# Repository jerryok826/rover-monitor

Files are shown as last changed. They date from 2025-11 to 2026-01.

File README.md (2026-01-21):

# Rover Monitor
Rover monitor is a simple info display for the JPL's open-source-rover project
# My initial Rover Testing
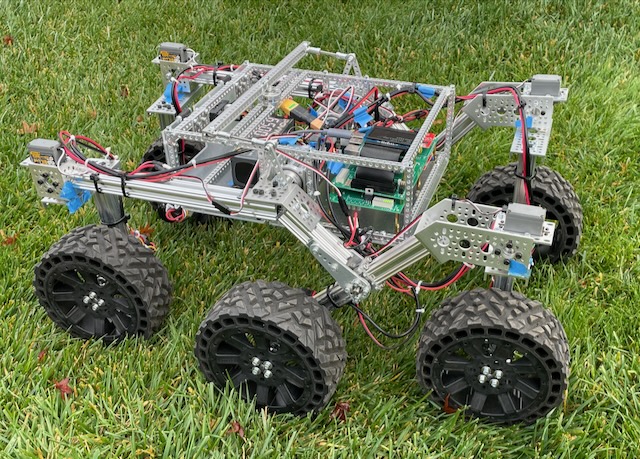
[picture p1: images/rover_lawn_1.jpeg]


# Rover info monitor.
### Rover ROS2 Off
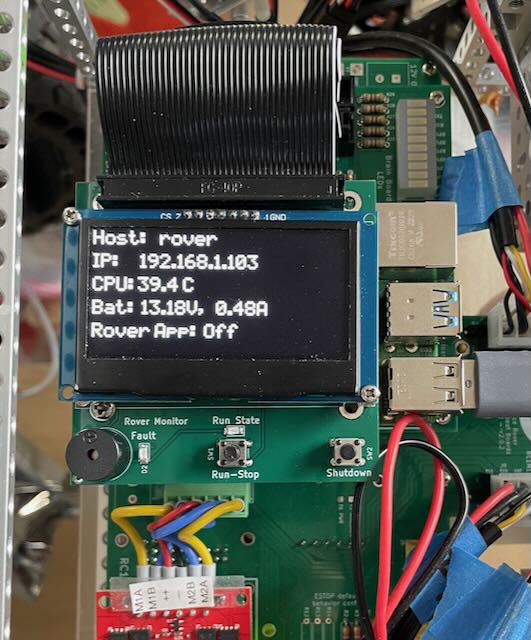
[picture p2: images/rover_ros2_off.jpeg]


### Rover ROS2 Running
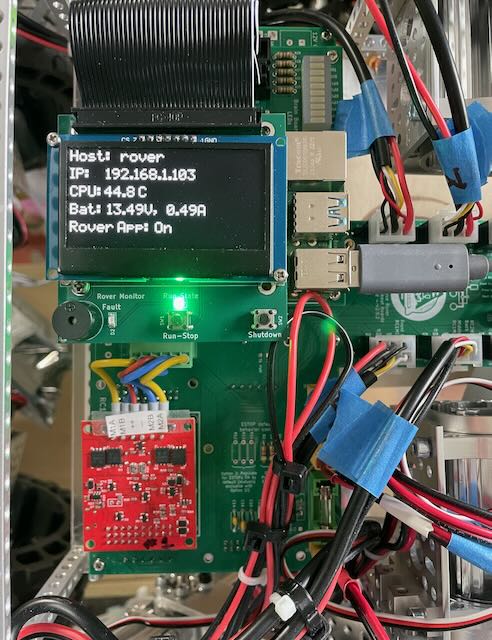
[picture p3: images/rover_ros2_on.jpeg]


### Voltage fault: Below 12.0 V
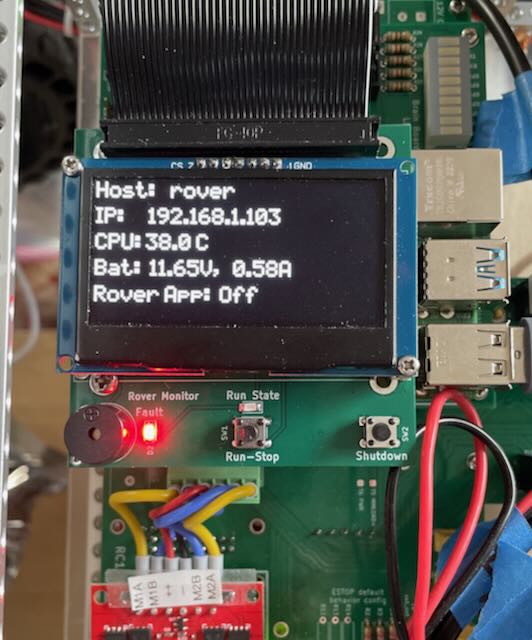
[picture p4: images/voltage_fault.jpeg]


## Rover Monitor Project Description
I wanted a convenient way to start/stop, shutdown and monitor the rover for problems. The board just uses the RPI's GPIO to drive the board with some C code. The code boots from startup and monitors the rover's battery voltage and current. It’s also convenient to have the rover's hostname for remote login. The V and I readings come from the rover's on board ina260 via i2c. Been using the board for login info and shutdown for about a month.

Monitor Features:
1. Local login info.
2. Rover shutdown button.
3. Rover ROS run and stop button.
4. Voltage and current monitoring with audio alarm on fault.
5. Monitor beeps when system has complteted booting and ready for operation.

### Project Status
Basically complete, except for a fault event detail line to the display. Below is the original prototype version.

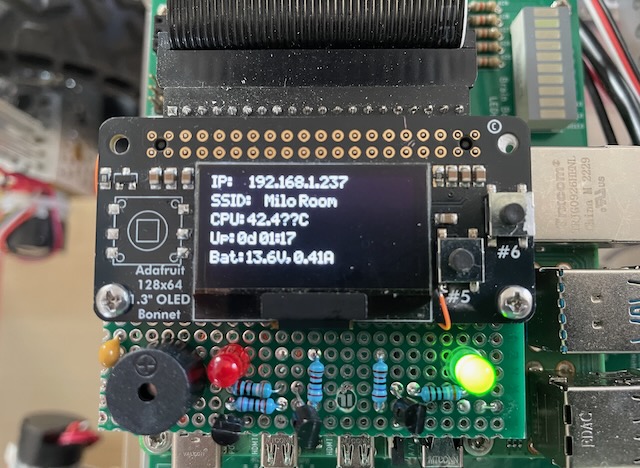
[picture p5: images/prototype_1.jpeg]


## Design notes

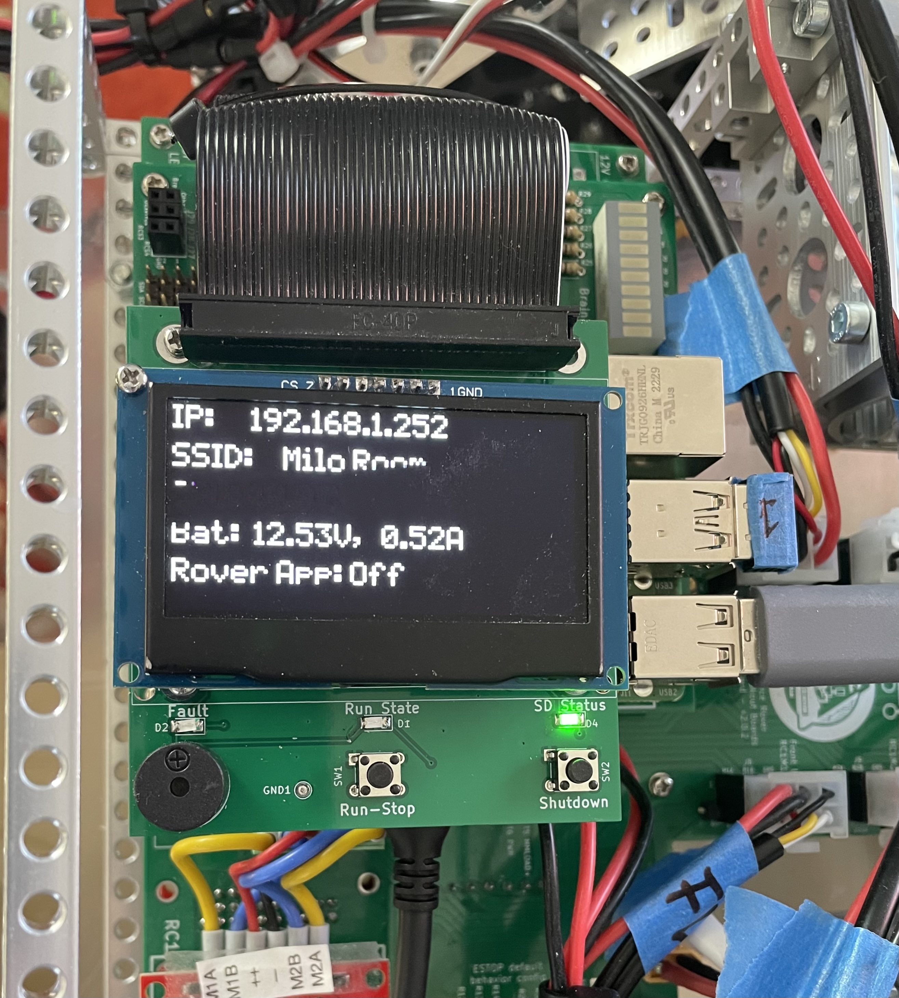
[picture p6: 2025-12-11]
images/rover_monitor_pcb.jpg

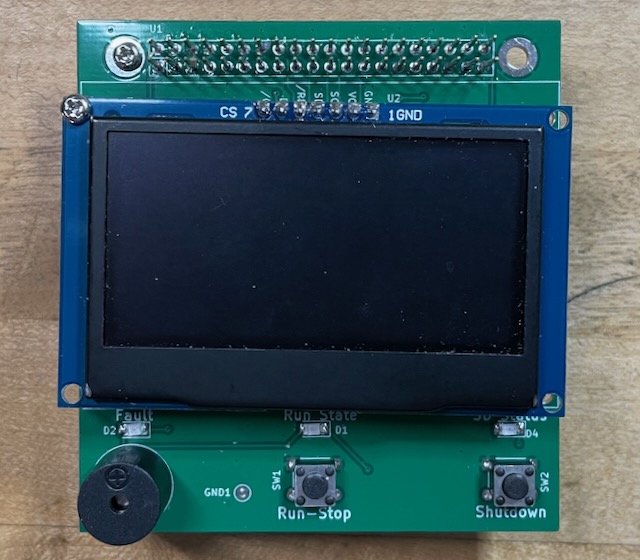
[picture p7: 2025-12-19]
images/oled_board_front.jpeg

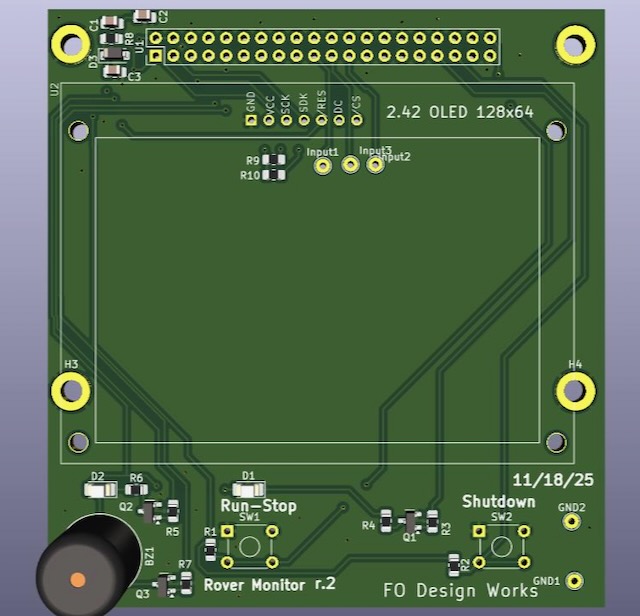
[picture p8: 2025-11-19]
images/rover_monitor_pcb_r2.jpeg

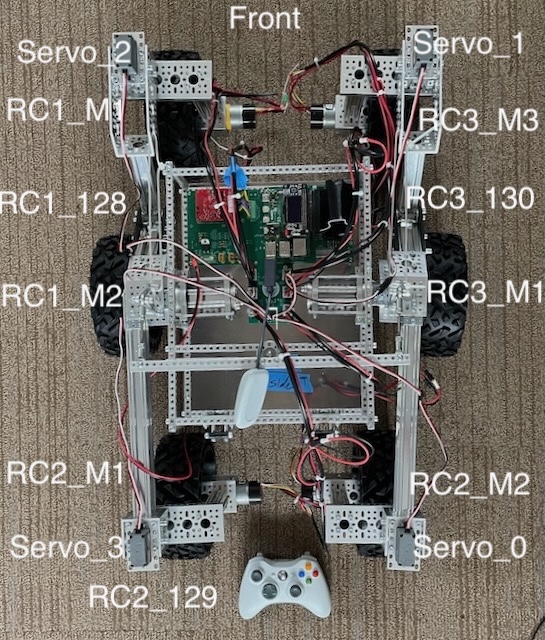
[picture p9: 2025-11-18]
images/jpl_rover_2.jpeg

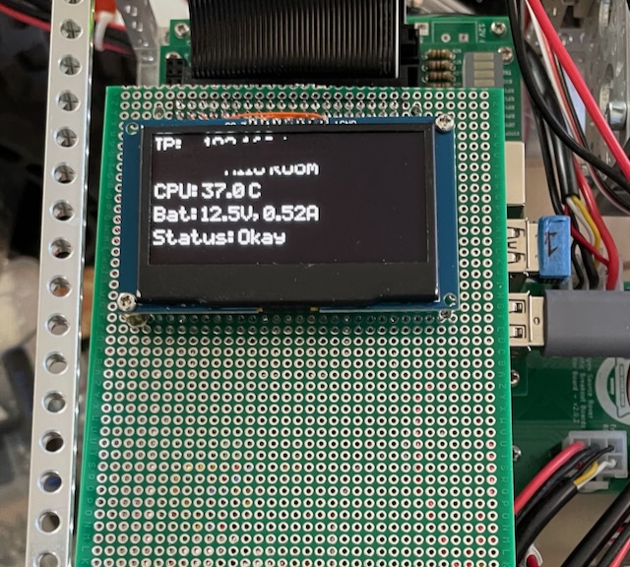
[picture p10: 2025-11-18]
images/oled_large.jpeg

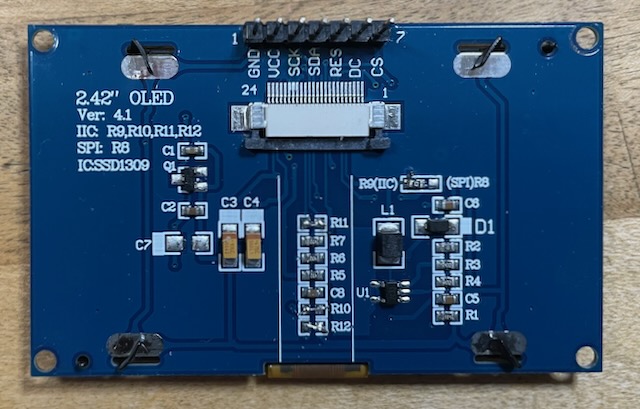
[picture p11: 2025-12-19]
images/oled_i2c.jpeg

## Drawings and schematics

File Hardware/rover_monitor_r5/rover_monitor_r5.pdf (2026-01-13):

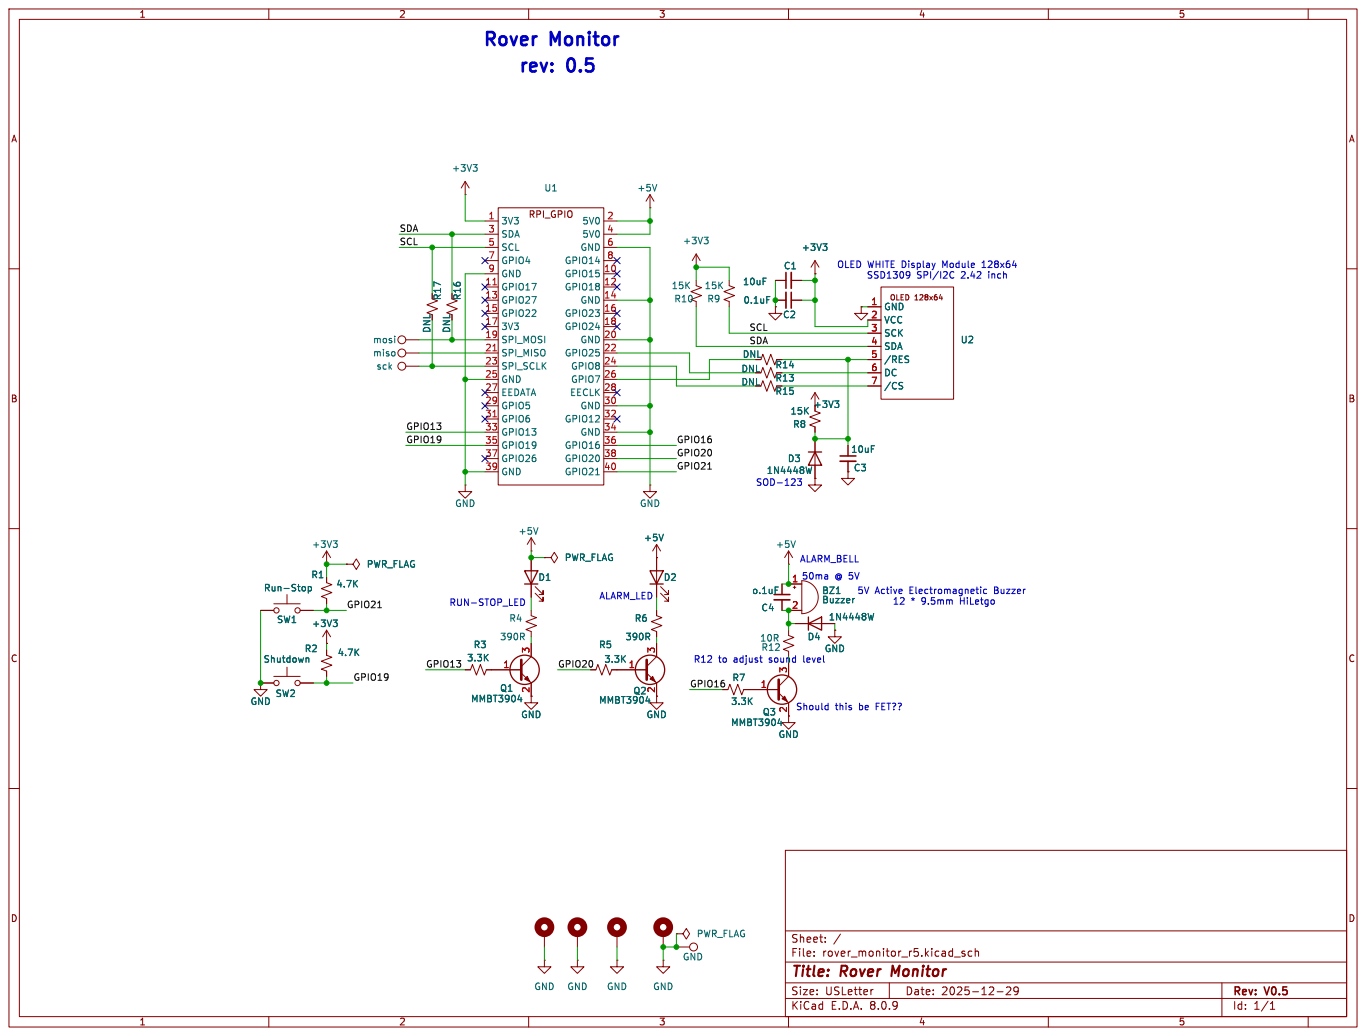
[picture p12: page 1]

Id: 1/1 Title: Rover Monitor File: rover_monitor_r5.kicad_sch Sheet: /

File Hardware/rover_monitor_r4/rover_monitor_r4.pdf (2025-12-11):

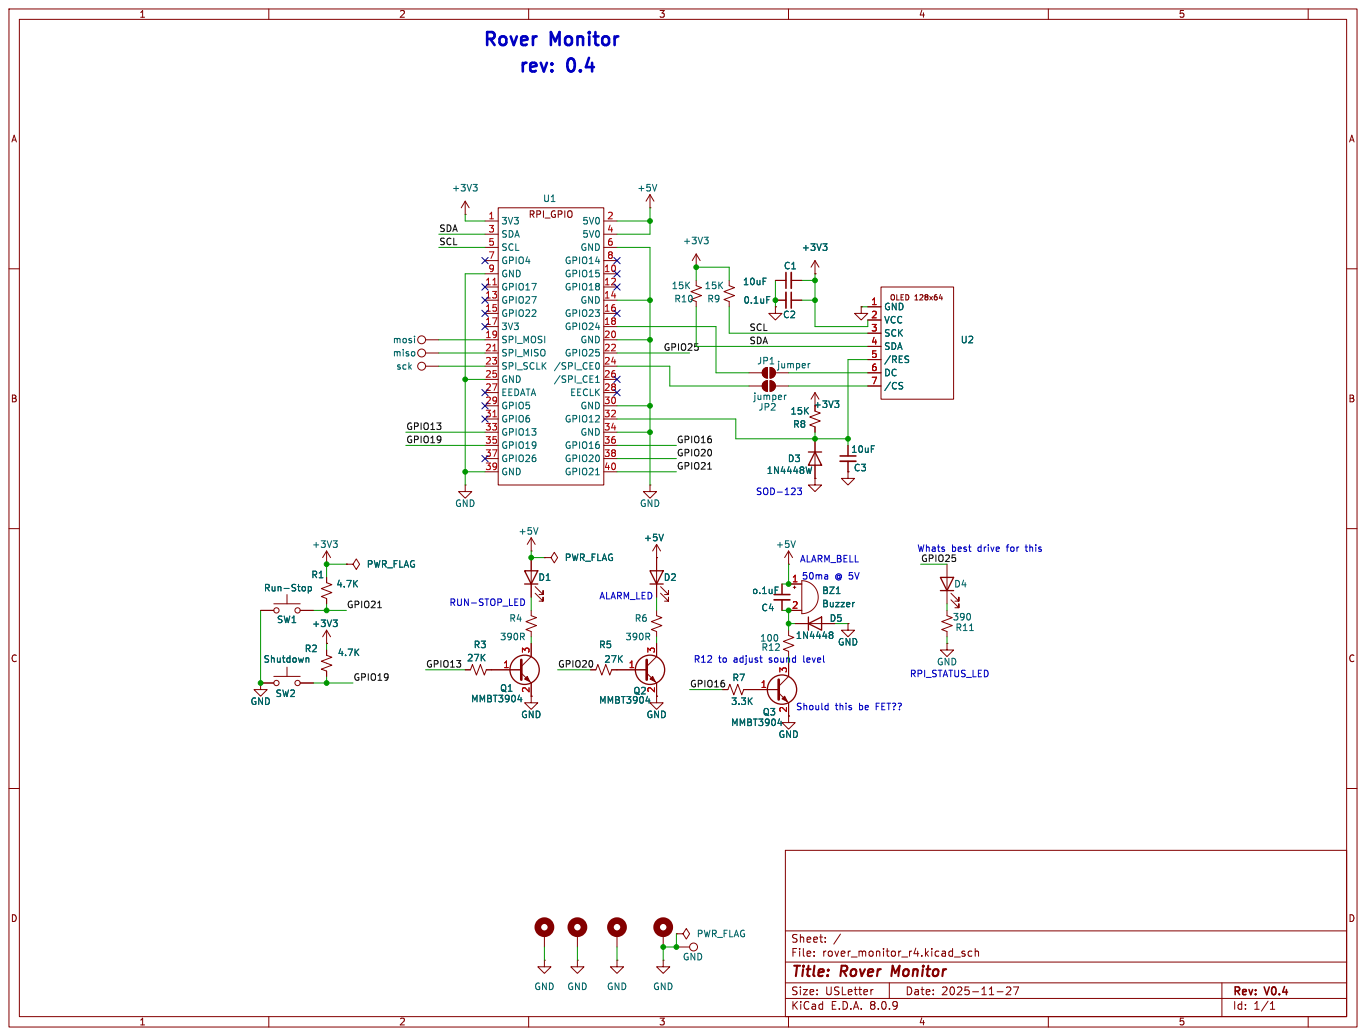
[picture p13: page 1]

2 3 Q3 MMBT3904GND GND GND GND GND

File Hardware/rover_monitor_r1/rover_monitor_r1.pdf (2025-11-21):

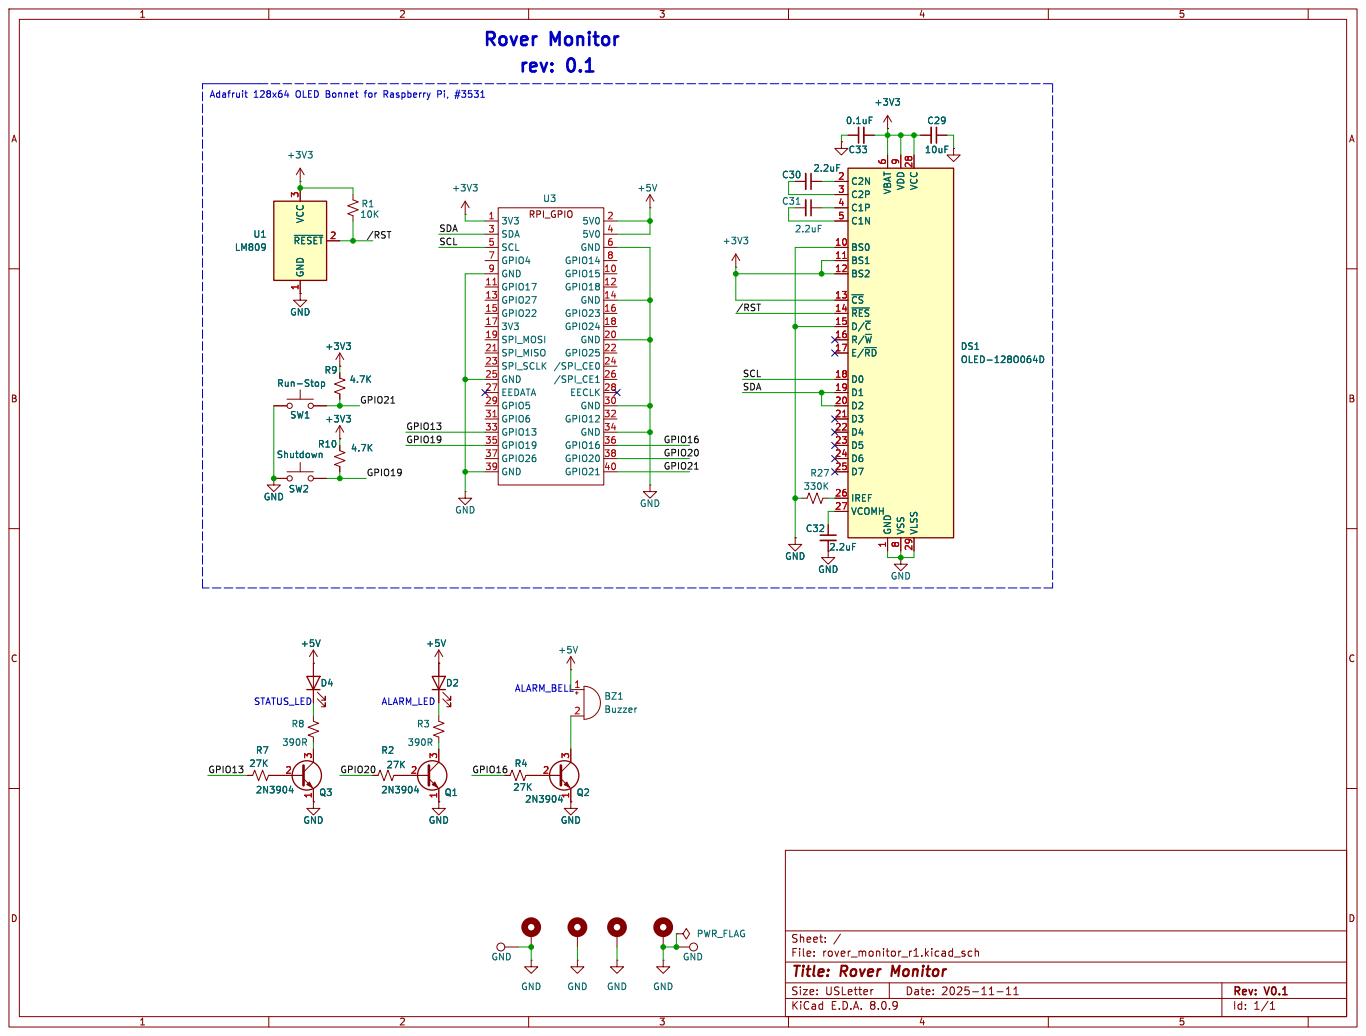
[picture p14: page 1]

Id: 1/1 Title: Rover Monitor File: rover_monitor_r1.kicad_sch Sheet: / +5V

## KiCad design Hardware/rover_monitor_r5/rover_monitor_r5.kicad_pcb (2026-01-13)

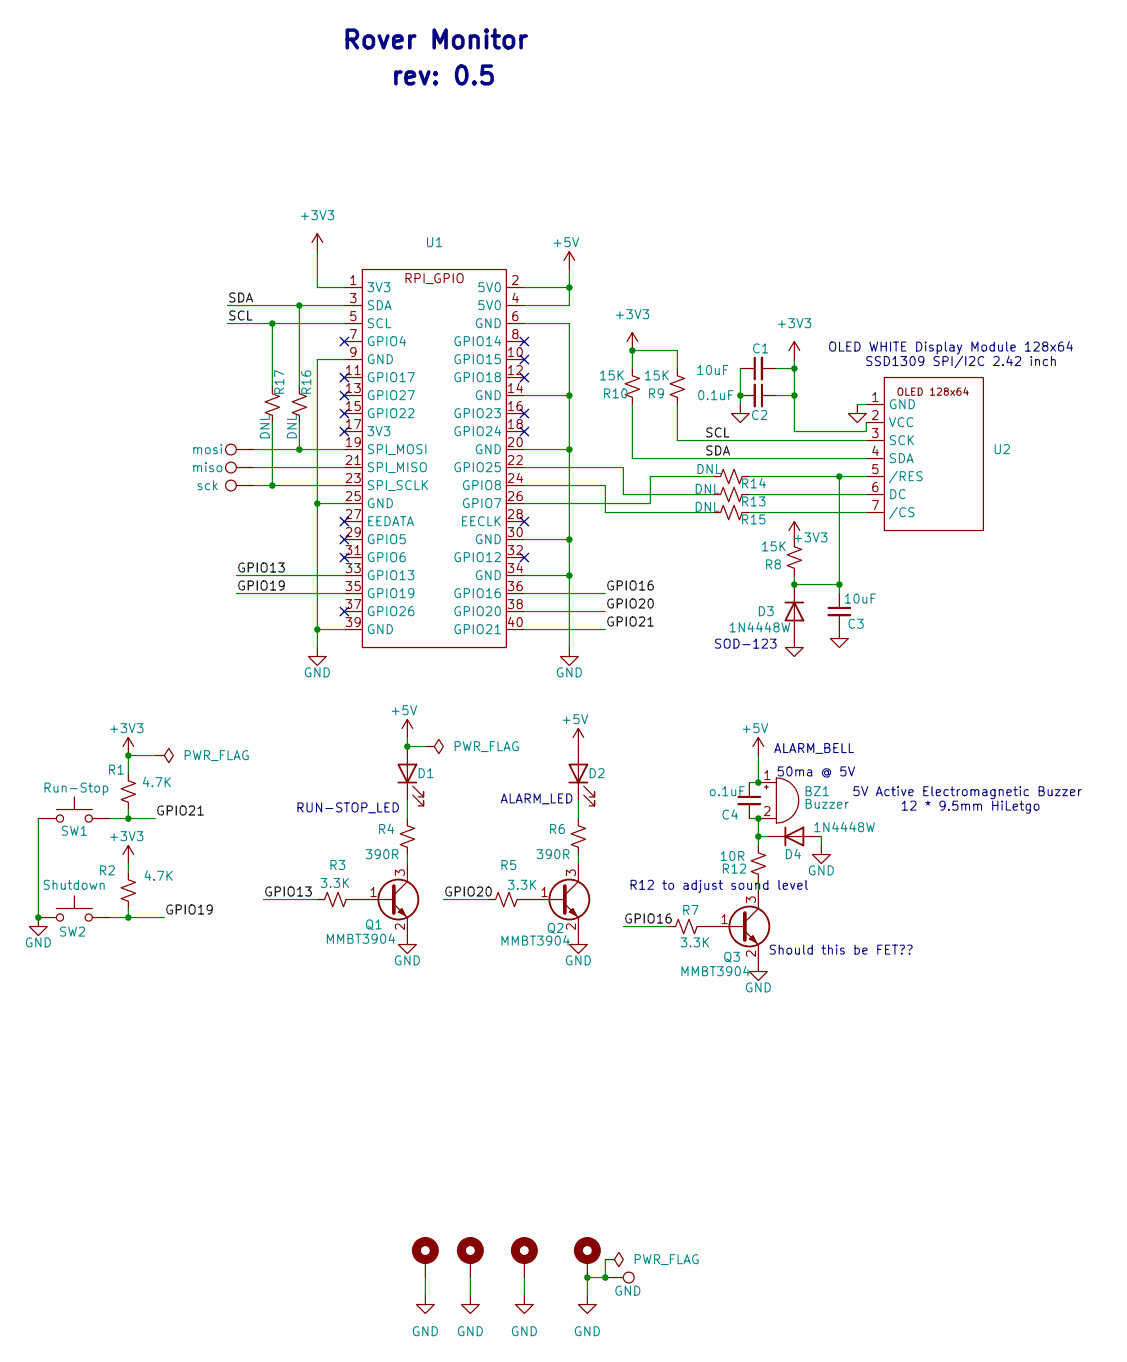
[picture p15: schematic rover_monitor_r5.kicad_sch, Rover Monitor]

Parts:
BZ1: Buzzer; Buzzer_12x9.5RM7.6
C1, C3: 10uF; C_0805_2012Metric_Pad1.18x1.45mm_HandSolder
C2: 0.1uF; C_0805_2012Metric_Pad1.18x1.45mm_HandSolder
C4: o.1uF; C_0805_2012Metric_Pad1.18x1.45mm_HandSolder
D1: Run-Stop; LED_1206_3216Metric_Pad1.42x1.75mm_HandSolder
D2: Alarm; LED_1206_3216Metric_Pad1.42x1.75mm_HandSolder
D3, D4: 1N4448W; D_SOD-123
GND1: GND; TestPoint_THTPad_D2.0mm_Drill1.0mm
H1, H2, H3, H4: MountingHole_Pad; MountingHole_3.2mm_M3_ISO7380_Pad_TopBottom
Q1, Q2, Q3: MMBT3904; SOT-23
R1, R2: 4.7K; R_0805_2012Metric_Pad1.20x1.40mm_HandSolder
R3, R5, R7: 3.3K; R_0805_2012Metric_Pad1.20x1.40mm_HandSolder
R4, R6: 390R; R_0805_2012Metric_Pad1.20x1.40mm_HandSolder
R8, R9, R10: 15K; R_0805_2012Metric_Pad1.20x1.40mm_HandSolder
R12: 10R; R_0805_2012Metric_Pad1.20x1.40mm_HandSolder
R13, R14, R15, R16, R17: DNL; R_0805_2012Metric_Pad1.20x1.40mm_HandSolder
SW1: Run-Stop; SW_TH_Tactile_Omron_B3F-10xx
SW2: Shutdown; SW_TH_Tactile_Omron_B3F-10xx
U1: PinHeader_2x20_P2.54mm_Vertical
U2: oled_128x64_r2
miso1: miso; TestPoint_THTPad_D2.0mm_Drill1.0mm
mosi1: mosi; TestPoint_THTPad_D2.0mm_Drill1.0mm
sck1: sck; TestPoint_THTPad_D2.0mm_Drill1.0mm

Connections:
+3V3: C1.2, C2.1, R1.1, R2.1, R8.1, R9.1, R10.1, U1.1 (3V3), U2.2 (VCC)
+5V: BZ1.1 (+), C4.1, D1.2 (A), D2.2 (A), U1.2 (5V0), U1.4 (5V0)
/GPIO13: R3.2, U1.33 (GPIO13)
/GPIO16: R7.2, U1.36 (GPIO16)
/GPIO19: R2.2, SW2.2, U1.35 (GPIO19)
/GPIO20: R5.2, U1.38 (GPIO20)
/GPIO21: R1.2, SW1.2, U1.40 (GPIO21)
/SCL: R9.2, R17.2, U1.5 (SCL), U2.3 (SCK)
/SDA: R10.2, R16.2, U1.3 (SDA), U2.4 (SDA)
GND: C1.1, C2.2, C3.2, D3.2 (A), D4.2 (A), GND1.1, H1.1, H2.1, H3.1, H4.1, Q1.2 (E), Q2.2 (E), Q3.2 (E), SW1.1, SW2.1, U1.6 (GND), U1.9 (GND), U1.14 (GND), U1.20 (GND), U1.25 (GND), U1.30 (GND), U1.34 (GND), U1.39 (GND), U2.1 (GND)
unnamed: BZ1.2 (-), C4.2, D4.1 (K), R12.1
unnamed: D1.1 (K), R4.1
unnamed: D2.1 (K), R6.1
unnamed: C3.1, D3.1 (K), R8.2, R14.2, U2.5 (/RES)
unnamed: Q1.1 (B), R3.1
unnamed: Q1.3 (C), R4.2
unnamed: Q2.1 (B), R5.1
unnamed: Q2.3 (C), R6.2
unnamed: Q3.1 (B), R7.1
unnamed: Q3.3 (C), R12.2
unnamed: R14.1, U1.26 (GPIO7)
unnamed: R15.1, U1.24 (GPIO8)
unnamed: R13.1, U1.22 (GPIO25)
unnamed: U1.21 (SPI_MISO), miso1.1
unnamed: R16.1, U1.19 (SPI_MOSI), mosi1.1
unnamed: R17.1, U1.23 (SPI_SCLK), sck1.1
unnamed: R13.2, U2.6 (DC)
unnamed: R15.2, U2.7 (/CS)

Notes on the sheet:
RUN-STOP_LED
ALARM_BELL
rev: 0.5
SOD-123
Rover Monitor
50ma @ 5V
Should this be FET??
OLED WHITE Display Module 128x64 SSD1309 SPI/I2C 2.42 inch
ALARM_LED
5V Active Electromagnetic Buzzer 12 * 9.5mm HiLetgo
R12 to adjust sound level

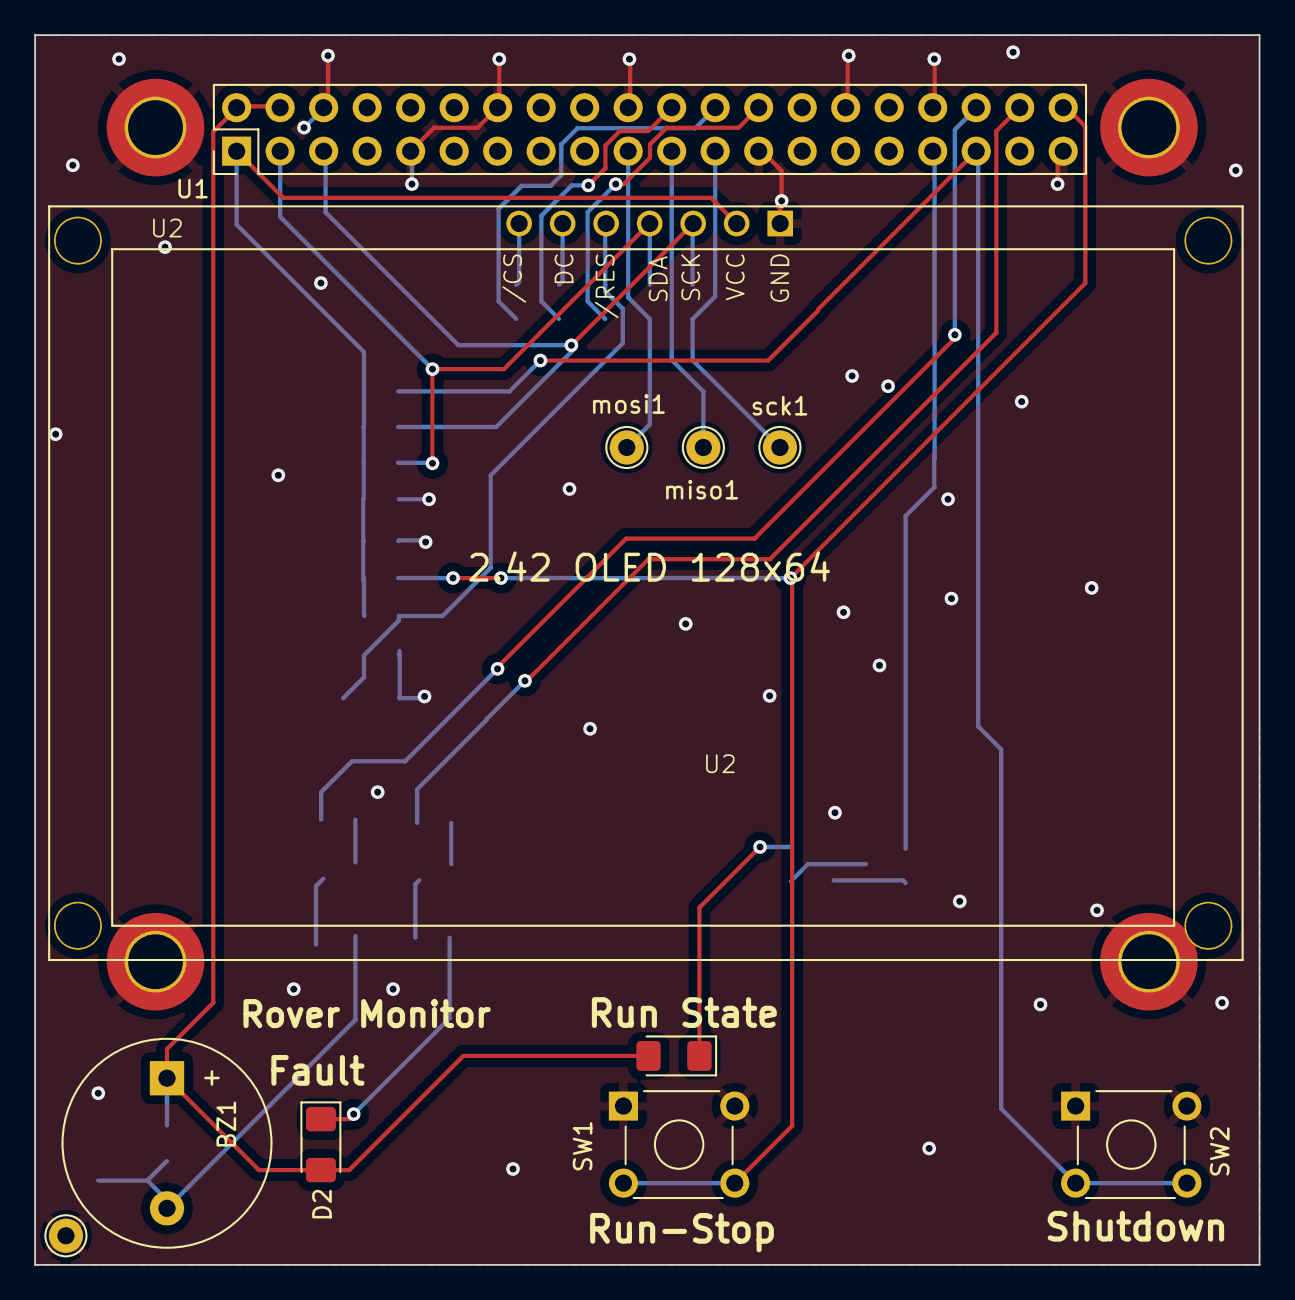
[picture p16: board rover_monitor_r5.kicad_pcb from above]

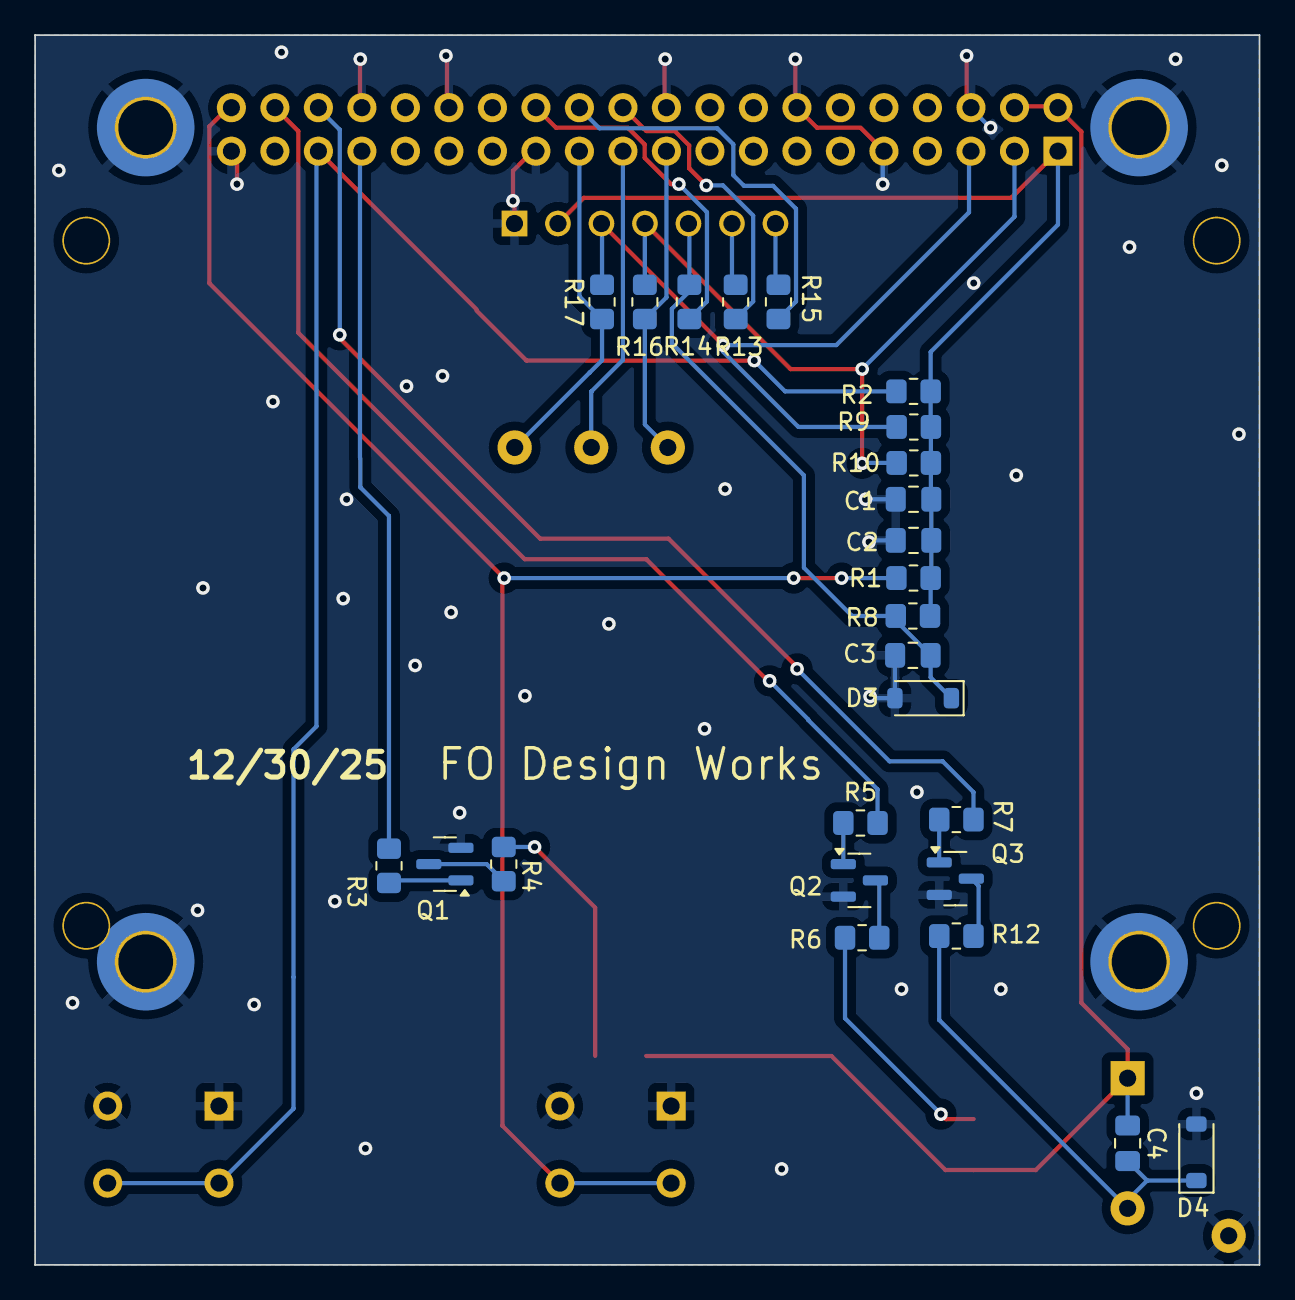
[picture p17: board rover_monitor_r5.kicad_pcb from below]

Board: 2 copper layers, 71.5 x 71.8 mm, 41 parts (25 on the bottom side), 28 nets.

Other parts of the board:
U2#2: oled_128x64_r2

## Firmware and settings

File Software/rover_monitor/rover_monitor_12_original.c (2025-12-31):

//
// Combines an SSD1306 128x64 I2C status display (IP/SSID/CPU Temp/Uptime)
// with a shutdown button on GPIO 19 and a status LED on GPIO 13 using libgpiod.
//
// Wiring (BCM numbering):
//   - OLED Bonnet (SSD1306) on I2C-1 (SDA/SCL) @ 0x3C
//   - Shutdown button: GPIO19 to GND (active-low). Use a physical pull-up or internal if configured.
//   - Status LED: GPIO13 + series resistor to 3V3 (active-high) or to GND (active-low; invert in code)
//
// Build:
//   gcc -O2 -o rover_monitor_12 rover_monitor_12.c os_calls.c ina260.c -lgpiod'
//
//  sudo cp pi_oled_shutdown_monitor_2 /usr/local/bin
//
//  sudo nano  /etc/systemd/system/ip2oled_monitor_bonnet.service
//
// Run (needs GPIO + I2C access):
//   sudo ./pi_oled_shutdown_monitor
//
// sudo systemctl stop  ip2oled_monitor_bonnet.service
// sudo cp pi_oled_shutdown_monitor_2  /usr/local/bin
// sudo systemctl start  ip2oled_monitor_bonnet.service
//
// systemd service example is provided after the code.


// indent -gnu -br -cli2 -lp -nut -l100 rover_monitor_12.c

#define _GNU_SOURCE
#include <math.h>
#include <gpiod.h>  // libgpiod v1.6.3
#include <arpa/inet.h>
#include <errno.h>
#include <fcntl.h>
#include <ifaddrs.h>
#include <linux/i2c-dev.h>
#include <net/if.h>
#include <netinet/in.h>
#include <signal.h>
#include <stdarg.h>
#include <stdbool.h>
#include <stdint.h>
#include <stdio.h>
#include <stdlib.h>
#include <string.h>
#include <sys/ioctl.h>
#include <sys/time.h>
#include <time.h>
#include <unistd.h>             // For sleep() in the main thread
#include <stdatomic.h>          // Required for atomic operations
#include <pthread.h>            // Required for pthreads
#include "ina260.h"
#include "os_calls.h"

#define VOLATGE_HIGH_LIMIT (16000.0)    // 16 volts
#define VOLATGE_LOW_LIMIT  (12000.0)    // 12 volts
#define CURRENT_HIGH_LIMIT  (7000.0)    // 7 amps
#define OLED_I2C_DEV   "/dev/i2c-1"
#define OLED_ADDR      0x3c     // 0x3C
#define CHIPNAME       "gpiochip0"
#define SHUTDOWN_BUTTON_PIN 19
#define GREEN_LED_PIN       13
#define RED_LED_PIN         20
#define ALARM_PIN           16
#define RUN_STOP_BUTTON_PIN 21
static int i2c_ina260_fd;
static int ina260_online = 0;
static int rover_run_state = 0;

// ======== Simple logging ========
static void
simple_logf (const char *fmt, ...)
{
  va_list ap;
  va_start (ap, fmt);
  vfprintf (stdout, fmt, ap);
  fprintf (stdout, "\n");
  fflush (stdout);
  va_end (ap);
}

// ======== OLED / SSD1306 minimal driver ========
#define SSD1306_WIDTH   128
#define SSD1306_HEIGHT   64
#define SSD1306_BUF_SZ  (SSD1306_WIDTH * SSD1306_HEIGHT / 8)

static int i2c_fd = -1;
static uint8_t oled_buf[SSD1306_BUF_SZ];

static int
i2c_open_dev (const char *dev, int addr)
{
  int fd = open (dev, O_RDWR);
  if (fd < 0)
    return -1;
  if (ioctl (fd, I2C_SLAVE, addr) < 0) {
    close (fd);
    return -1;
  }
  return fd;
}

static int
ssd1306_cmd (uint8_t c)
{
  uint8_t buf[2] = { 0x00, c }; // control byte 0x00 = command
  if (write (i2c_fd, buf, 2) != 2)
    return -1;
  return 0;
}

static int
ssd1306_cmd2 (uint8_t c1, uint8_t c2)
{
  if (ssd1306_cmd (c1) < 0)
    return -1;
  if (ssd1306_cmd (c2) < 0)
    return -1;
  return 0;
}

static int
ssd1306_data (const uint8_t *data, size_t len)
{
  // Send as chunks prefixed with 0x40 control byte.
  uint8_t chunk[17];
  chunk[0] = 0x40;
  while (len > 0) {
    size_t n = len > 16 ? 16 : len;
    memcpy (&chunk[1], data, n);
    if (write (i2c_fd, chunk, n + 1) != (ssize_t) (n + 1))
      return -1;
    data += n;
    len -= n;
  }
  return 0;
}

static int
ssd1306_init (void)
{
  if ((i2c_fd = i2c_open_dev (OLED_I2C_DEV, OLED_ADDR)) < 0) {
    perror ("i2c_open_dev");
    return -1;
  }
  // Init sequence (typical)
  if (ssd1306_cmd (0xAE) < 0)
    return -1;                  // display off
  if (ssd1306_cmd2 (0xD5, 0x80) < 0)
    return -1;                  // clock divide
  if (ssd1306_cmd2 (0xA8, 0x3F) < 0)
    return -1;                  // multiplex
  if (ssd1306_cmd2 (0xD3, 0x00) < 0)
    return -1;                  // display offset
  if (ssd1306_cmd (0x40) < 0)
    return -1;                  // start line
  if (ssd1306_cmd2 (0x8D, 0x14) < 0)
    return -1;                  // charge pump
  if (ssd1306_cmd2 (0x20, 0x00) < 0)
    return -1;                  // memory mode: horizontal

  // rotated the disply around
  if (ssd1306_cmd (0xA1) < 0)
    return -1;                  // seg remap, cmd 0xA0 sets the segment remap to normal, while 0xA1 reverses it.
  if (ssd1306_cmd (0xC8) < 0)
    return -1;                  // COM scan dec, cmd 0xC0 sets the scan direction to normal, while 0xC8 reverses it.

  if (ssd1306_cmd2 (0xDA, 0x12) < 0)
    return -1;                  // compins
  if (ssd1306_cmd2 (0x81, 0xCF) < 0)
    return -1;                  // contrast
  if (ssd1306_cmd2 (0xD9, 0xF1) < 0)
    return -1;                  // precharge
  if (ssd1306_cmd2 (0xDB, 0x40) < 0)
    return -1;                  // vcom detect
  if (ssd1306_cmd (0xA4) < 0)
    return -1;                  // entire display on (resume)
  if (ssd1306_cmd (0xA6) < 0)
    return -1;                  // normal display

  if (ssd1306_cmd (0xAF) < 0)
    return -1;                  // display on
  memset (oled_buf, 0x00, sizeof (oled_buf));
  return 0;
}

static void
ssd1306_clear (void)
{
  memset (oled_buf, 0x00, sizeof (oled_buf));
}

static void
ssd1306_set_pixel (int x, int y, bool on)
{
  if (x < 0 || x >= SSD1306_WIDTH || y < 0 || y >= SSD1306_HEIGHT)
    return;
  size_t idx = (y / 8) * SSD1306_WIDTH + x;
  uint8_t bit = 1 << (y & 7);
  if (on)
    oled_buf[idx] |= bit;
  else
    oled_buf[idx] &= ~bit;
}

static void
ssd1306_hline (int x, int y, int w, bool on)
{
  for (int i = 0; i < w; ++i)
    ssd1306_set_pixel (x + i, y, on);
}

static int
ssd1306_update (void)
{
  if (ssd1306_cmd2 (0x21, 0x00) < 0)
    return -1;                  // set column addr: start 0
  if (ssd1306_cmd (0x7F) < 0)
    return -1;                  // end 127
  if (ssd1306_cmd2 (0x22, 0x00) < 0)
    return -1;                  // set page addr: start 0
  if (ssd1306_cmd (0x07) < 0)
    return -1;                  // end 7
  return ssd1306_data (oled_buf, sizeof (oled_buf));
}

// 5x7 Font (ASCII 32..127), each char 5 columns, LSB = top pixel.
// (Shortened comment; full table included.)
static const uint8_t font5x7[96][5] = {
  {0x00, 0x00, 0x00, 0x00, 0x00},       // 32 ' '
  {0x00, 0x00, 0x5F, 0x00, 0x00},       // 33 '!'
  {0x00, 0x07, 0x00, 0x07, 0x00},       // 34 '"'
  {0x14, 0x7F, 0x14, 0x7F, 0x14},       // 35 '#'
  {0x24, 0x2A, 0x7F, 0x2A, 0x12},       // 36 '$'
  {0x23, 0x13, 0x08, 0x64, 0x62},       // 37 '%'
  {0x36, 0x49, 0x55, 0x22, 0x50},       // 38 '&'
  {0x00, 0x05, 0x03, 0x00, 0x00},       // 39 '''
  {0x00, 0x1C, 0x22, 0x41, 0x00},       // 40 '('
  {0x00, 0x41, 0x22, 0x1C, 0x00},       // 41 ')'
  {0x14, 0x08, 0x3E, 0x08, 0x14},       // 42 '*'
  {0x08, 0x08, 0x3E, 0x08, 0x08},       // 43 '+'
  {0x00, 0x50, 0x30, 0x00, 0x00},       // 44 ','
  {0x08, 0x08, 0x08, 0x08, 0x08},       // 45 '-'
  {0x00, 0x60, 0x60, 0x00, 0x00},       // 46 '.'
  {0x20, 0x10, 0x08, 0x04, 0x02},       // 47 '/'
  {0x3E, 0x51, 0x49, 0x45, 0x3E},       // 48 '0'
  {0x00, 0x42, 0x7F, 0x40, 0x00},       // 49 '1'
  {0x42, 0x61, 0x51, 0x49, 0x46},       // 50 '2'
  {0x21, 0x41, 0x45, 0x4B, 0x31},       // 51 '3'
  {0x18, 0x14, 0x12, 0x7F, 0x10},       // 52 '4'
  {0x27, 0x45, 0x45, 0x45, 0x39},       // 53 '5'
  {0x3C, 0x4A, 0x49, 0x49, 0x30},       // 54 '6'
  {0x01, 0x71, 0x09, 0x05, 0x03},       // 55 '7'
  {0x36, 0x49, 0x49, 0x49, 0x36},       // 56 '8'
  {0x06, 0x49, 0x49, 0x29, 0x1E},       // 57 '9'
  {0x00, 0x36, 0x36, 0x00, 0x00},       // 58 ':'
  {0x00, 0x56, 0x36, 0x00, 0x00},       // 59 ';'
  {0x08, 0x14, 0x22, 0x41, 0x00},       // 60 '<'
  {0x14, 0x14, 0x14, 0x14, 0x14},       // 61 '='
  {0x00, 0x41, 0x22, 0x14, 0x08},       // 62 '>'
  {0x02, 0x01, 0x51, 0x09, 0x06},       // 63 '?'
  {0x32, 0x49, 0x79, 0x41, 0x3E},       // 64 '@'
  {0x7E, 0x11, 0x11, 0x11, 0x7E},       // 65 'A'
  {0x7F, 0x49, 0x49, 0x49, 0x36},       // 66 'B'
  {0x3E, 0x41, 0x41, 0x41, 0x22},       // 67 'C'
  {0x7F, 0x41, 0x41, 0x22, 0x1C},       // 68 'D'
  {0x7F, 0x49, 0x49, 0x49, 0x41},       // 69 'E'
  {0x7F, 0x09, 0x09, 0x09, 0x01},       // 70 'F'
  {0x3E, 0x41, 0x49, 0x49, 0x7A},       // 71 'G'
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
  {0x02, 0x04, 0x08, 0x10, 0x20},       // 92 backslash
  {0x00, 0x41, 0x41, 0x7F, 0x00},       // 93 ']'
  {0x04, 0x02, 0x01, 0x02, 0x04},       // 94 '^'
  {0x80, 0x80, 0x80, 0x80, 0x80},       // 95 '_'
  {0x00, 0x01, 0x02, 0x04, 0x00},       // 96 '`'
  {0x20, 0x54, 0x54, 0x54, 0x78},       // 97 'a'
  {0x7F, 0x48, 0x44, 0x44, 0x38},       // 98 'b'
  {0x38, 0x44, 0x44, 0x44, 0x20},       // 99 'c'
  {0x38, 0x44, 0x44, 0x48, 0x7F},       // 100 'd'
  {0x38, 0x54, 0x54, 0x54, 0x18},       // 101 'e'
  {0x08, 0x7E, 0x09, 0x01, 0x02},       // 102 'f'
  {0x0C, 0x52, 0x52, 0x52, 0x3E},       // 103 'g'
  {0x7F, 0x08, 0x04, 0x04, 0x78},       // 104 'h'
  {0x00, 0x44, 0x7D, 0x40, 0x00},       // 105 'i'
  {0x20, 0x40, 0x44, 0x3D, 0x00},       // 106 'j'
  {0x7F, 0x10, 0x28, 0x44, 0x00},       // 107 'k'
  {0x00, 0x41, 0x7F, 0x40, 0x00},       // 108 'l'
  {0x7C, 0x04, 0x18, 0x04, 0x78},       // 109 'm'
  {0x7C, 0x08, 0x04, 0x04, 0x78},       // 110 'n'
  {0x38, 0x44, 0x44, 0x44, 0x38},       // 111 'o'
  {0x7C, 0x14, 0x14, 0x14, 0x08},       // 112 'p'
  {0x08, 0x14, 0x14, 0x14, 0x7C},       // 113 'q'
  {0x7C, 0x08, 0x04, 0x04, 0x08},       // 114 'r'
  {0x48, 0x54, 0x54, 0x54, 0x20},       // 115 's'
  {0x04, 0x3F, 0x44, 0x40, 0x20},       // 116 't'
  {0x3C, 0x40, 0x40, 0x20, 0x7C},       // 117 'u'
  {0x1C, 0x20, 0x40, 0x20, 0x1C},       // 118 'v'
  {0x3C, 0x40, 0x30, 0x40, 0x3C},       // 119 'w'
  {0x44, 0x28, 0x10, 0x28, 0x44},       // 120 'x'
  {0x0C, 0x50, 0x50, 0x50, 0x3C},       // 121 'y'
  {0x44, 0x64, 0x54, 0x4C, 0x44},       // 122 'z'
  {0x08, 0x36, 0x41, 0x41, 0x00},       // 123 '{'
  {0x00, 0x00, 0x7F, 0x00, 0x00},       // 124 '|'
  {0x00, 0x41, 0x41, 0x36, 0x08},       // 125 '}'
  {0x08, 0x04, 0x08, 0x10, 0x08}        // 126 '~'
};

// Compute proportional width by trimming empty columns
static int
glyph_width (uint8_t glyph[5])
{
  int left = 0, right = 4;
  while (left < 5) {
    if (glyph[left])
      break;
    left++;
  }
  while (right >= 0) {
    if (glyph[right])
      break;
    right--;
  }
  int w = right - left + 1;
  if (w <= 0)
    w = 1;
  if (w > 5)
    w = 5;
  return w;
}

static void
draw_char_prop (int x, int y, char c)
{
  if (c < 32 || c > 127)
    c = '?';
  const uint8_t *g = font5x7[c - 32];
  // Determine visible columns
  int left = 0, right = 4;
  while (left < 5 && g[left] == 0)
    left++;
  while (right >= 0 && g[right] == 0)
    right--;
  if (right < left) {
    right = left;
  }                             // at least 1 col
  int w = right - left + 1;
  for (int col = 0; col < w; ++col) {
    uint8_t bits = g[left + col];
    for (int row = 0; row < 7; ++row) {
      bool on = (bits >> row) & 1;
      ssd1306_set_pixel (x + col, y + row, on);
    }
  }
}

static int
draw_text_prop (int x, int y, const char *s)
{
  int cursor = x;
  for (; *s; ++s) {
    char c = *s;
    if (c == '\n') {
      y += 10;
      cursor = x;
      continue;
    }
    if (c < 32 || c > 127)
      c = '?';
    uint8_t glyph[5];
    memcpy (glyph, font5x7[c - 32], 5);
    // draw
    draw_char_prop (cursor, y, c);
    int w = glyph_width (glyph);
    cursor += w + 1;            // 1px spacing
    if (cursor >= SSD1306_WIDTH)
      break;
  }
  return cursor;
}

// ======== System info helpers ========
static int
get_hostname (char *out, size_t outlen)
{
  int rc = -1;

  memset(out,0,outlen);

  // Call gethostname() to retrieve the name
  if (gethostname(out, outlen) == 0) {
//       printf("Local Hostname: %s\n", out);
        rc = 0;
  } else {
        // If gethostname fails, print an error message
        perror("gethostname failed");
        return rc;
  }
  return rc;
}

static int
get_ip_address (char *out, size_t outlen)
{
  struct ifaddrs *ifaddr, *ifa;
  if (getifaddrs (&ifaddr) == -1)
    return -1;
  int rc = -1;
  for (ifa = ifaddr; ifa != NULL; ifa = ifa->ifa_next) {
    if (!ifa->ifa_addr)
      continue;
    if (ifa->ifa_addr->sa_family == AF_INET) {
      unsigned int flags = ifa->ifa_flags;
      if (!(flags & IFF_UP) || (flags & IFF_LOOPBACK))
        continue;
      struct sockaddr_in *sa = (struct sockaddr_in *) ifa->ifa_addr;
      if (inet_ntop (AF_INET, &sa->sin_addr, out, outlen)) {
        rc = 0;
        break;
      }
    }
  }
  freeifaddrs (ifaddr);
  return rc;
}

static int
get_wifi_ssid (char *out, size_t outlen)
{
  // Use iwgetid -r if available (simple + robust)
  FILE *fp = popen ("iwgetid -r 2>/dev/null", "r");
  if (!fp)
    return -1;
  if (!fgets (out, (int) outlen, fp)) {
    pclose (fp);
    return -1;
  }
  pclose (fp);
  // strip newline
  size_t n = strlen (out);
  while (n && (out[n - 1] == '\n' || out[n - 1] == '\r')) {
    out[--n] = 0;
  }
  if (n == 0)
    return -1;
  return 0;
}

static int
get_cpu_temp_c (double *outC)
{
  FILE *f = fopen ("/sys/class/thermal/thermal_zone0/temp", "r");
  if (!f)
    return -1;
  long t = 0;
  if (fscanf (f, "%ld", &t) != 1) {
    fclose (f);
    return -1;
  }
  fclose (f);
  *outC = t / 1000.0;
  return 0;
}

static void
fmt_uptime (char *out, size_t outlen)
{
  // Read from /proc/uptime
  FILE *f = fopen ("/proc/uptime", "r");
  double up = 0.0;
  if (f) {
    int i = fscanf (f, "%lf", &up);
    fclose (f);
  }
  unsigned long s = (unsigned long) (up + 0.5);
  unsigned long d = s / 86400;
  s %= 86400;
  unsigned long h = s / 3600;
  s %= 3600;
  unsigned long m = s / 60;
  snprintf (out, outlen, "%lud %02lu:%02lu", d, h, m);
}

static void
get_ina260_status (float *voltage_mv, float *current_ma)
{
  *voltage_mv = ina260_read_voltage_mV (i2c_ina260_fd);
  *current_ma = ina260_read_current_mA (i2c_ina260_fd);
}

// ======== GPIO / shutdown handling ========
static volatile sig_atomic_t keepRunning = 1;

static void
sigint_handler (int sig)
{
  (void) sig;
  keepRunning = 0;
}

static struct gpiod_chip *chip = NULL;
static struct gpiod_line *btn_line = NULL;
static struct gpiod_line *rs_btn_line = NULL;
static struct gpiod_line *green_led_line = NULL;
static struct gpiod_line *red_led_line = NULL;
static struct gpiod_line *bell_line = NULL;
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
int
main (void)
{
  signal (SIGINT, sigint_handler);
  signal (SIGTERM, sigint_handler);

  if (is_raspberry_pi()) {
        printf("Running on a Raspberry Pi.\n");
  } else {
        printf("Not running on a Raspberry Pi. Bye\n");
        return 1;
  }

  pthread_t sound_tid;

  // Create the background sound thread
  if (pthread_create (&sound_tid, NULL, background_sound_thread, NULL) != 0) {
    perror ("pthread_create error");
    return 1;
  }

  ina260_online = 0;
  if (ina260_setup () == 0) {
    ina260_online = 1;
  }
  else {
    fprintf (stderr, "ina260 init failed.\n");
  }

  if (ssd1306_init () < 0) {
    fprintf (stderr, "SSD1306 init failed.\n");
    return 1;
  }
  if (gpio_init () < 0) {
    fprintf (stderr, "GPIO init failed.\n");
    return 1;
  }

  char hostname[50];
  get_hostname (hostname, sizeof(hostname));

#if 0
  simple_logf ("Service started. Button GPIO%d, LED GPIO%d, OLED on %s addr 0x%02X",
               BUTTON_PIN, LED_PIN, OLED_I2C_DEV, OLED_ADDR);
#endif

  // Startup LED blink & bell
  sound_enabled = true;
  sleep (1);
  sound_enabled = false;

  // Steady on while running
  gpio_set_green_led (0);
  gpio_set_red_led (0);
  gpio_set_bell (0);

  char ip[64] = { 0 }, last_ip[64] = { 0 };
  char ssid[64] = { 0 }, last_ssid[64] = { 0 };
  double tempC = 0.0, last_tempC = -999.0;
  float voltage_mv = 0.0, current_ma = 0.0;
  char upbuf[32] = { 0 };
  int tick_cntr = 0;
//  int rover_run_state = 0;

  // Initial read
  get_ip_address (ip, sizeof ip);
  if (get_wifi_ssid (ssid, sizeof ssid) != 0)
    strncpy (ssid, "—", sizeof ssid);
  get_cpu_temp_c (&tempC);
  fmt_uptime (upbuf, sizeof upbuf);
  get_ina260_status (&voltage_mv, &current_ma);

  draw_status_screen (hostname, ip, ssid, tempC, upbuf, voltage_mv, current_ma);
  strncpy (last_ip, ip, sizeof last_ip);
  strncpy (last_ssid, ssid, sizeof last_ssid);
  last_tempC = tempC;

  // Main loop: refresh every ~1s, handle button events
  while (keepRunning) {
    // Periodic screen refresh
    bool changed = false;
    // Wait up to 1s for a button event
    struct timespec timeout = {.tv_sec = 1,.tv_nsec = 0 };

    int event_btn_1 = gpiod_line_event_wait (btn_line, &timeout);
    if (event_btn_1 < 0) {
      perror ("event_btn_1 gpiod_line_event_wait");
      break;
    }
    if (event_btn_1 == 1) {
      // Read and process event (debounced: only act on falling edge and ignore repeats for 500ms)
      struct gpiod_line_event ev;
      if (gpiod_line_event_read (btn_line, &ev) == 0) {
        if (ev.event_type == GPIOD_LINE_EVENT_FALLING_EDGE) {
          simple_logf ("Button pressed: initiating shutdown");
          draw_message_center ("Shutting down...");
          // turn off LED to indicate it's safe to cut power *after* OS halts
          gpio_set_green_led (1);
          gpio_set_red_led (1);
          gpio_set_bell (0);

          // brief delay so the message is visible
          usleep (800 * 1000);
          // Request shutdown
          int s = system ("shutdown -h now");
          break;
        }
      }
      // simple debounce delay
      usleep (150 * 1000);
    }

    struct timespec timeout2 = {.tv_sec = 1,.tv_nsec = 0 };
    int event_btn_2 = gpiod_line_event_wait (rs_btn_line, &timeout2);
    if (event_btn_2 < 0) {
      perror ("event_btn_2 gpiod_line_event_wait");
      break;
    }
    if (event_btn_2 == 1) {
      // Read and process event (debounced: only act on falling edge and ignore repeats for 500ms)
      struct gpiod_line_event ev;
      int system_call_status = 0;
      if (gpiod_line_event_read (rs_btn_line, &ev) == 0) {
        if (ev.event_type == GPIOD_LINE_EVENT_FALLING_EDGE) {
          simple_logf ("RS Button pressed: ??");
          draw_message_center ("Bell button pressed");
          // Toggle Rover run state
          if (rover_run_state != 0) {
            printf ("Stop Rover\n");
            rover_run_state = 0;
            stop_rover();

            printf ("'stop_rover.sh' script finished.\n");
            gpio_set_green_led (0);
          }
          else {
            printf ("Start Rover\n");
            rover_run_state = 1;
//                       stop_rover(); // make sure everthing thing is stopped
            usleep (10 * 1000); // 10 millsec ?

            start_rover ();

            printf ("'start_rover.sh' script finished.\n");
            gpio_set_green_led (1);
          }

          // brief delay so the message is visible
          usleep (800 * 1000);
        }
      }
      // simple debounce delay
      usleep (150 * 1000);
      changed = true;
    }

    // Periodic screen refresh
//        bool changed = false;

    if (get_ip_address (ip, sizeof ip) == 0) {
      if (strcmp (ip, last_ip) != 0) {
        changed = true;
        strncpy (last_ip, ip, sizeof last_ip);
      }
    }
    else {
      if (strcmp (last_ip, "—") != 0) {
        strncpy (last_ip, "—", sizeof last_ip);
        changed = true;
      }
    }

    if (get_wifi_ssid (ssid, sizeof ssid) == 0) {
      if (strcmp (ssid, last_ssid) != 0) {
        changed = true;
        strncpy (last_ssid, ssid, sizeof last_ssid);
      }
    }
    else {
      if (strcmp (last_ssid, "—") != 0) {
        strncpy (last_ssid, "—", sizeof last_ssid);
        changed = true;
      }
    }

    if (get_cpu_temp_c (&tempC) == 0) {
      // Update if temp changed by >= 0.5 C
      if (fabs (tempC - last_tempC) >= 0.5) {
        changed = true;
        last_tempC = tempC;
      }
    }

    fmt_uptime (upbuf, sizeof upbuf);

    voltage_mv = 0.0;
    current_ma = 0.0;
    if (ina260_online) {        // check if ina260 is connedted. 
      get_ina260_status (&voltage_mv, &current_ma);     // ina260_str
//            printf("Volts: %3.3fmV, Current: %3.3fmA\n", voltage_mv, current_ma);
      sound_enabled = false;
    }
    else {
//            printf("Status:ina260 off line\n");
      strcpy (status_line, "Status:ina260 off line");
    }

    if (ina260_online == 1) {
      if ((voltage_mv < VOLATGE_LOW_LIMIT) && (tick_cntr & 1)) {
        //    printf("Voltage fault: %3.3f V\n",voltage_mv);
        sound_enabled = true;
        changed = true;         // ??
        strcpy (status_line, "Under Voltage Fault");
        // Should we do something else here? ie shut down ROS2??
      }
      else if ((voltage_mv > VOLATGE_HIGH_LIMIT) && (tick_cntr & 1)) {
        sound_enabled = true;
        strcpy (status_line, "Over Voltage Fault");
        // Should we do something else here? ie shut down ROS2??
      }
      else if ((current_ma > CURRENT_HIGH_LIMIT) && (tick_cntr & 1)) {
        sound_enabled = true;
        strcpy (status_line, "Over Current Fault");
        // Should we do something else here? ie shut down ROS2??
      }
      else {
        sound_enabled = false;
        strcpy (status_line, "Status: Okay");
      }
    }

    if (changed) {
      draw_status_screen (hostname,last_ip, last_ssid, last_tempC, upbuf, voltage_mv, current_ma);
    }
    else {
      // Still refresh once every ~10 seconds to keep uptime current
      static int counter = 0;
      counter = (counter + 1) % 10;
      if (counter == 0)
        draw_status_screen (hostname,last_ip, last_ssid, last_tempC, upbuf, voltage_mv, current_ma); // 1200.0, 500.0);
    }
    tick_cntr++;
  }

  gpio_cleanup ();
  if (i2c_fd >= 0)
    close (i2c_fd);
  return 0;
}

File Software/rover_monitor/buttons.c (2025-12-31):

/* buttons.c
 *
 * Implementation for libgpiod v1.6.3 button helper.
 *
 * Build (with a separate main.c):
 *   gcc -Wall -O2 -c buttons.c
 *   gcc -Wall -O2 main.c buttons.o -lgpiod -lpthread -o app
 *
 * Optional unit test main is at bottom under #if 0.
 */

#include "buttons.h"

#include <gpiod.h>
#include <errno.h>
#include <pthread.h>
#include <stdint.h>
#include <stdio.h>
#include <stdlib.h>
#include <string.h>
#include <time.h>
#include <unistd.h>   // pause()

// ---------- Configuration ----------
#ifndef BUTTONS_GPIOCHIP_PATH
#define BUTTONS_GPIOCHIP_PATH "/dev/gpiochip0"
#endif

#ifndef BUTTONS_DEBOUNCE_MS
#define BUTTONS_DEBOUNCE_MS 40
#endif

#ifndef BUTTONS_RELEASE_POLL_MS
#define BUTTONS_RELEASE_POLL_MS 5
#endif
// -----------------------------------

/* =========================
 * Private / internal section
 * ========================= */

struct btn_ctx {
    int pin;
    struct gpiod_line *line;

    pthread_t thread;
    int thread_started;

    button_cb_t cb;

    int64_t last_accept_ns;
    int64_t debounce_ns;
};

static pthread_mutex_t g_lock = PTHREAD_MUTEX_INITIALIZER;
static struct gpiod_chip *g_chip = NULL;
static struct btn_ctx g_btn[2];
static int g_inited = 0;
static volatile int g_stop = 0;

static void _print_err(const char *where) {
    fprintf(stderr, "%s: %s\n", where, strerror(errno));
}

static inline int64_t _ts_to_ns(const struct timespec *ts) {
    return (int64_t)ts->tv_sec * 1000000000LL + (int64_t)ts->tv_nsec;
}

static void _sleep_ms(int ms) {
    struct timespec ts;
    ts.tv_sec = ms / 1000;
    ts.tv_nsec = (long)(ms % 1000) * 1000L * 1000L;
    nanosleep(&ts, NULL);
}

/* Pull-up wiring: released=1, pressed=0 */
static void _wait_for_release_pullup(struct gpiod_line *line, int pin) {
    while (!g_stop) {
        int v = gpiod_line_get_value(line);
        if (v < 0) {
            fprintf(stderr, "GPIO %d get_value error: %s\n", pin, strerror(errno));
            return; // during shutdown, don't hard-exit
        }
        if (v == 1) return; // released
        _sleep_ms(BUTTONS_RELEASE_POLL_MS);
    }
}

static void *_button_thread(void *arg) {
    struct btn_ctx *ctx = (struct btn_ctx *)arg;

    for (;;) {
        if (g_stop) break;

        /* Use a finite timeout so shutdown doesn't hang waiting forever */
        struct timespec timeout = { .tv_sec = 0, .tv_nsec = 200 * 1000 * 1000 }; // 200ms
        int w = gpiod_line_event_wait(ctx->line, &timeout);
        if (w < 0) {
            if (g_stop) break;
            fprintf(stderr, "GPIO %d event_wait error: %s\n", ctx->pin, strerror(errno));
            break;
        }
        if (w == 0) continue; // timeout, loop to check g_stop

        /* Drain queued events */
        for (;;) {
            if (g_stop) break;

            struct gpiod_line_event ev;
            if (gpiod_line_event_read(ctx->line, &ev) < 0) {
                if (errno == EAGAIN) { errno = 0; break; }
                if (g_stop) break;
                fprintf(stderr, "GPIO %d event_read error: %s\n", ctx->pin, strerror(errno));
                break;
            }

            /* press-only for pull-up: FALLING edge (1 -> 0) */
            if (ev.event_type != GPIOD_LINE_EVENT_FALLING_EDGE)
                continue;

            /* debounce */
            int64_t now_ns = _ts_to_ns(&ev.ts);
            if (ctx->last_accept_ns >= 0 &&
                (now_ns - ctx->last_accept_ns) < ctx->debounce_ns) {
                continue;
            }
            ctx->last_accept_ns = now_ns;

            /* callback */
            button_cb_t cb_local = NULL;

            /* Take a local copy under lock so callback registration is thread-safe */
            pthread_mutex_lock(&g_lock);
            cb_local = ctx->cb;
            pthread_mutex_unlock(&g_lock);

            if (cb_local) cb_local(ctx->pin);

            /* release gate */
            _wait_for_release_pullup(ctx->line, ctx->pin);
        }
    }

    return NULL;
}

static struct btn_ctx *_find_ctx(int pin_num) {
    for (int i = 0; i < 2; i++) {
        if (g_btn[i].pin == pin_num) return &g_btn[i];
    }
    return NULL;
}

/* =========================
 * Public API section
 * ========================= */

int buttons_init(int pin_num1, int pin_num2) {
    pthread_mutex_lock(&g_lock);

    if (g_inited) {
        fprintf(stderr, "buttons_init: already initialized\n");
        pthread_mutex_unlock(&g_lock);
        return -1;
    }
    if (pin_num1 == pin_num2) {
        fprintf(stderr, "buttons_init: pins must be different\n");
        pthread_mutex_unlock(&g_lock);
        return -1;
    }

    g_stop = 0;
    memset(g_btn, 0, sizeof(g_btn));

    g_chip = gpiod_chip_open(BUTTONS_GPIOCHIP_PATH);
    if (!g_chip) {
        _print_err("gpiod_chip_open");
        pthread_mutex_unlock(&g_lock);
        return -1;
    }

    g_btn[0].pin = pin_num1;
    g_btn[1].pin = pin_num2;

    for (int i = 0; i < 2; i++) {
        g_btn[i].last_accept_ns = -1;
        g_btn[i].debounce_ns = (int64_t)BUTTONS_DEBOUNCE_MS * 1000LL * 1000LL;
        g_btn[i].cb = NULL;

        g_btn[i].line = gpiod_chip_get_line(g_chip, g_btn[i].pin);
        if (!g_btn[i].line) {
            fprintf(stderr, "gpiod_chip_get_line failed for GPIO %d\n", g_btn[i].pin);
            pthread_mutex_unlock(&g_lock);
            buttons_shutdown(); // cleanup partial init
            return -1;
        }

        if (gpiod_line_request_falling_edge_events(g_btn[i].line, "buttons_lib") < 0) {
            fprintf(stderr, "request_falling_edge_events failed for GPIO %d: %s\n",
                    g_btn[i].pin, strerror(errno));
            pthread_mutex_unlock(&g_lock);
            buttons_shutdown(); // cleanup partial init
            return -1;
        }
    }

    for (int i = 0; i < 2; i++) {
        if (pthread_create(&g_btn[i].thread, NULL, _button_thread, &g_btn[i]) != 0) {
            fprintf(stderr, "pthread_create failed for GPIO %d\n", g_btn[i].pin);
            pthread_mutex_unlock(&g_lock);
            buttons_shutdown(); // cleanup partial init
            return -1;
        }
        g_btn[i].thread_started = 1;
    }

    g_inited = 1;
    pthread_mutex_unlock(&g_lock);
    return 0;
}

int button_callback(int pin_num, button_cb_t cb) {
    pthread_mutex_lock(&g_lock);

    if (!g_inited) {
        fprintf(stderr, "button_callback: buttons_init() must be called first\n");
        pthread_mutex_unlock(&g_lock);
        return -1;
    }

    struct btn_ctx *ctx = _find_ctx(pin_num);
    if (!ctx) {
        fprintf(stderr, "button_callback: pin %d not initialized\n", pin_num);
        pthread_mutex_unlock(&g_lock);
        return -1;
    }

    ctx->cb = cb;
    pthread_mutex_unlock(&g_lock);
    return 0;
}
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

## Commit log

2025-11-21 update sch
    [rover_monitor_r1.kicad_sch]
2025-11-21 rename gerber file
2025-12-11 update power readout support
2025-12-19 correct rover stop support
    [os_calls.c]
2025-12-31 better button support
2025-12-31 breakout ssd1306 driver
2026-01-01 add gpio output driver
